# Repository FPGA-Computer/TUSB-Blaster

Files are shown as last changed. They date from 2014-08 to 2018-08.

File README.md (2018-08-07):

The TUSB3410 USB stack was loosely based on Micah Dowty's polling based
USB driver, but was heavily modifed by me using TI's app notes and
source code examples. The resulting code is a mix of interrupt code and
polling. 

This is a clone of Altera USB Blaster based on the work of Kolja Waschk,
ixo.de. The code is ported to TI TUSB3410 USB to Serial converter chip
which is found in TI's MSP430 programmers and some very old cell phone
USB Serial interface dongles. 

TUSB3410 has a very slow microcontroller core. There are much better
chips out there. This is meant to serve as a demo of the USB stack and
to show that the chip can works as a USB JTAG device for OpenOCD and USB
Blaster clone in less than 3kB firmware.

TUSB3410 has onchip SRAM for firmware and you'll need to use my command
line util: load3410.exe to download its firmware.  Use libusb to make up a
.inf file/driver for it to stop window popup asking for drivers.

TI's apps loader util can also be used as an alternative.

License: Individual source files without copyright notices are written
by me and are distributed under GPL ver 2 or newer.

TUSB source code is compiled with SDCC 3.3.  I used Programmer's Notepad
as my IDE.  Win32 Util can be compileed with Pelles C for windows.

TUSB Blaster schematic/layout are Eagle CAD 6.5.0 files.

Project page: http://hw-by-design.blogspot.com/2018/08/tusb-blaster.html

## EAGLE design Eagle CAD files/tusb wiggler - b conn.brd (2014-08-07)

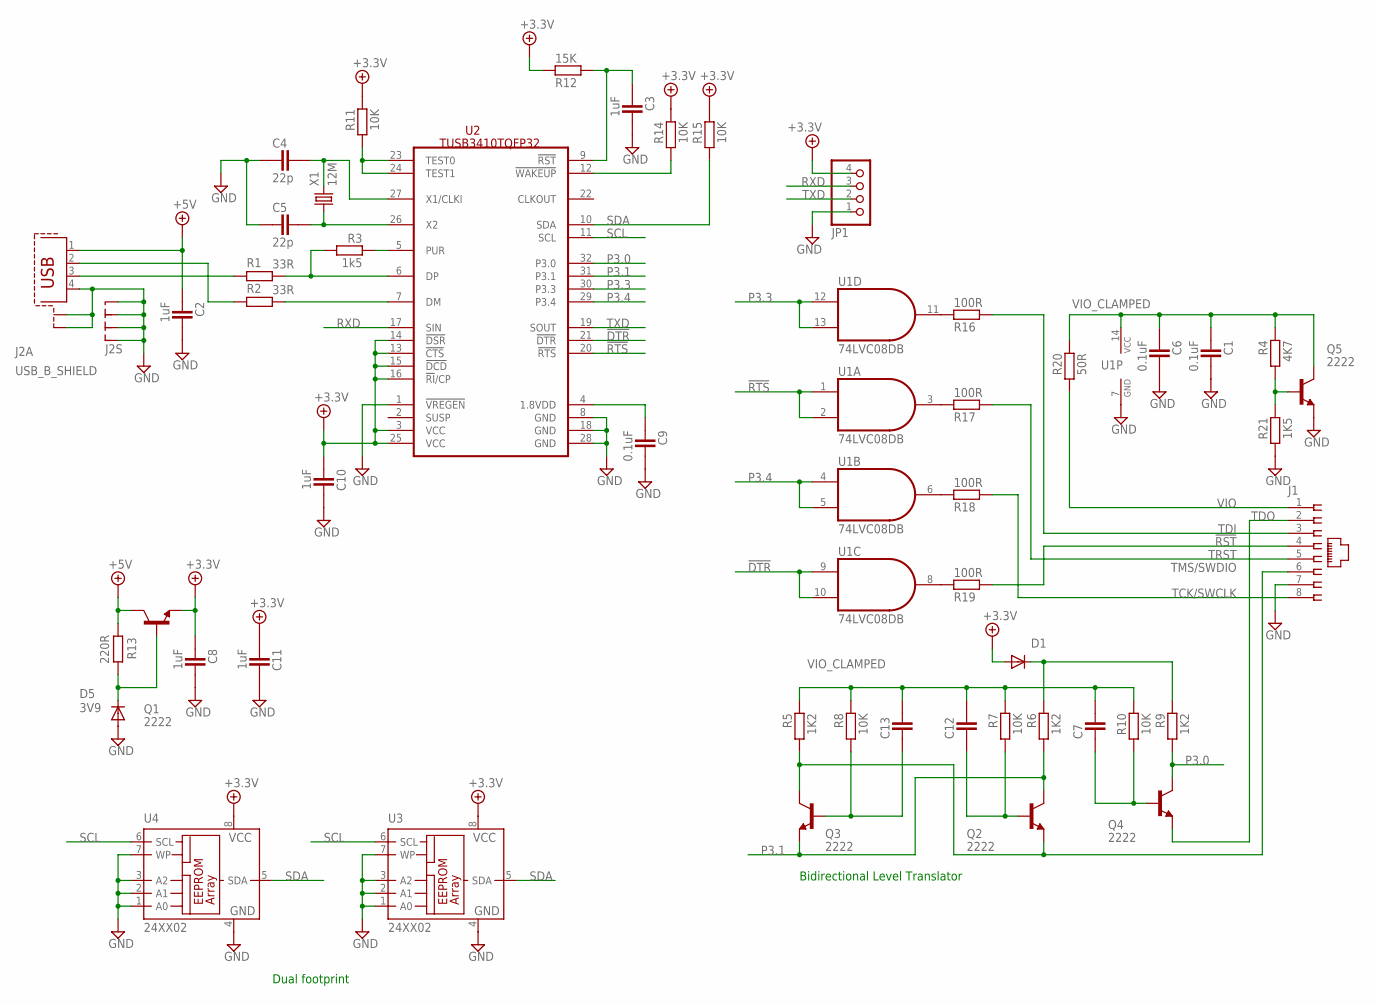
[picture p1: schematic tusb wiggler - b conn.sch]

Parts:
C1: 0.1uF; CAPC3215X168N
C2, C3, C8, C10, C11: 1uF; CAPC1608X92N
C4, C5: 22p; CAP2012X70N
C6: 0.1uF; CAPC1608X92N
C7, C12, C13: CAPACITOR_0805N; CAP2012X70N
C9: 0.1uF; CAP2012X70N
D1: DIODE-SOD110-W; SOD110-W
D5: 3V9; MELF-MLL41
J1: 520426-4
J2: USB_B_SHIELD; PN61729-S
JP1: PINHD-1X4_2.54; 1X04
Q1, Q2, Q3, Q4, Q5: 2222; SOT95P280X135-3N
R1, R2: 33R; RESC1608X55N
R3: 1k5; RESC1608X55N
R4: 4K7; RESC1608X55N
R5, R6, R9: 1K2; RESC1608X55N
R7, R8, R10, R11, R14, R15: 10K; RESC1608X55N
R12: 15K; RESC1608X55N
R13: 220R; RESC1608X55N
R16, R17, R18, R19: 100R; RESC3115X70N
R20: 50R; RESC1608X55N
R21: 1K5; RESC1608X55N
U1: 74LVC08DB; TSSOP14
U2: TUSB3410TQFP32; TQFP32-08
U3: 24XX02; TSSOP8
U4: 24XX02; SO-08
X1: 12M; HC49UP

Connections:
!DTR: U1.9 (I0), U1.10 (I1), U2.21 (!DTR)
!RST: J1.4, R19.2
!RTS: U1.1 (I0), U1.2 (I1), U2.20 (!RTS)
+3.3V: C8.1, C10.1, C11.1, D1.A, JP1.4, Q1.2 (E), R11.1, R12.1, R14.1, R15.1, U2.3 (VCC), U2.13 (!CTS), U2.14 (!DSR), U2.15 (!DCD), U2.16 (!RI!/CP), U2.25 (VCC), U3.8 (VCC), U4.8 (VCC)
+5V: C2.1, J2.1, Q1.3 (C), R13.1
GND: C1.2, C2.2, C3.2, C4.1, C5.1, C6.2, C8.2, C9.2, C10.2, C11.2, D5.A, J1.7, J2.4, J2.G1 (S1), J2.G2 (S1), J2.G3 (S2), J2.G4 (S2), J2.G5 (S3), J2.G6 (S4), JP1.1, Q5.2 (E), R21.2, U1.7 (GND), U2.1 (!VREGEN), U2.8 (GND), U2.18 (GND), U2.28 (GND), U3.1 (A0), U3.2 (A1), U3.3 (A2), U3.4 (GND), U3.7 (WP), U4.1 (A0), U4.2 (A1), U4.3 (A2), U4.4 (GND), U4.7 (WP)
unnamed: J2.3, R1.1
unnamed: C12.1, Q2.1 (B), R7.2
unnamed: C7.1, Q4.1 (B), R10.2
unnamed: C13.1, Q3.1 (B), R8.2
unnamed: R19.1, U1.8 (O)
unnamed: R11.2, U2.23 (TEST0), U2.24 (TEST1)
unnamed: C3.1, R12.2, U2.9 (!RST)
unnamed: R16.1, U1.11 (O)
unnamed: R17.1, U1.3 (O)
unnamed: R18.1, U1.6 (O)
unnamed: Q5.1 (B), R4.2, R21.1
unnamed: D1.C, R6.1, R9.1
unnamed: R14.2, U2.12 (!WAKEUP)
unnamed: J2.2, R2.1
unnamed: R1.2, R3.2, U2.6 (DP)
unnamed: R2.2, U2.7 (DM)
unnamed: D5.C, Q1.1 (B), R13.2
unnamed: C4.2, U2.27 (X1/CLKI), X1.2
unnamed: C5.2, U2.26 (X2), X1.1
unnamed: C9.1, U2.4 (1.8VDD)
unnamed: R3.1, U2.5 (PUR)
P3.0: Q4.3 (C), R9.2, U2.32 (P3.0)
P3.1: Q2.3 (C), Q3.2 (E), R6.2, U2.31 (P3.1)
P3.3: U1.12 (I0), U1.13 (I1), U2.30 (P3.3)
P3.4: U1.4 (I0), U1.5 (I1), U2.29 (P3.4)
RXD: JP1.3, U2.17 (SIN)
SCL: U2.11 (SCL), U3.6 (SCL), U4.6 (SCL)
SDA: R15.2, U2.10 (SDA), U3.5 (SDA), U4.5 (SDA)
TCK/SWCLK: J1.8, R18.2
TDI: J1.3, R16.2
TDO: J1.2, Q4.2 (E)
TMS/SWDIO: J1.6, Q2.2 (E), Q3.3 (C), R5.2
TRST: J1.5, R17.2
TXD: JP1.2, U2.19 (SOUT)
VIO: J1.1, R20.2
VIO_CLAMPED: C1.1, C6.1, C7.2, C12.2, C13.2, Q5.3 (C), R4.1, R5.1, R7.1, R8.1, R10.1, R20.1, U1.14 (VCC)

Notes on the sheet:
Bidirectional Level Translator
Dual footprint

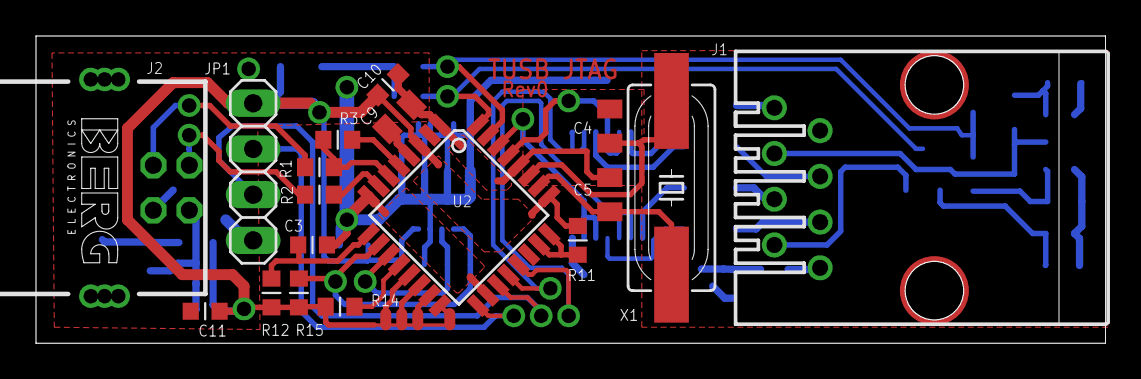
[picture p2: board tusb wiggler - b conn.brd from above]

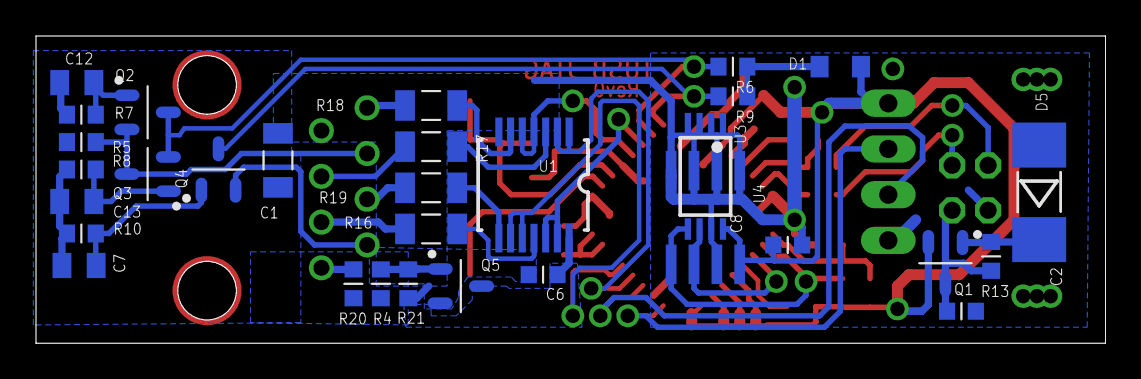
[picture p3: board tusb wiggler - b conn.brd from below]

Board: 2 copper layers, 59.4 x 17.1 mm, 49 parts (31 on the bottom side), 42 nets.

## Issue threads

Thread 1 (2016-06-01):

Porting to EFM8UB1 MCU ?

gh-jmg, 2016-06-01:
This looks a very cool project, but the TUSB3410 is quite expensive ($6+), and needs a Crystal.
Since you started this, SiLabs have released low cost 1T 8051 USB devices, that may be a better fit ?

I also see here http://ixo-jtag.sourceforge.net/archive/ixo_de_usb_jtag.html
that author started C8051F32x/F34x porting some years back, and those parts are predecessors to the EFM8UB1. (earliest ones were 24MHz SysCLK, 48MHz USB, newer are 48MHz for both CPU & USB)

Mouser shows EFM8UB10F8G-C-QFN20 for **81c 1+**
There are also 8k, 16k choices and QFN20, QFN28 or QSOP24 packages.
The newest EFM8UB1 (2016) also have a boot-loader, allowing simpler firmware updates.

I've been looking to see if the SPI port can be used dynamically for the byte-level ByteBlaster, but this will need some testing on the hand-over details between Bit-Mode and Byte-Mode.
SPI has a 4 byte FIFO and can do 48MHz/(2 * (SPI0CKR + 1)) bit rates (suggests 12MHz max), so that should manage the bulk transfers of JTAG well.

Software-only JTAG is of course simpler, and could be used for proof of concept work.

FPGA-Computer, 2016-08-21:
I actually used EFM8UB1F16 chips in here https://github.com/FPGA-Computer/Battery-Analyzer
Just that the project hasn't progressed to the point of working firmware.  Things are in limbo.

I don't have much interest in OpenOCD these days ever since they have broken a few things intentionally.  This project is released as is as there are few sources of USB drivers outside of the official source code.

Closed 2016-08-21.

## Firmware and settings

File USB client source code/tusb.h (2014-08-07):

/*-------------------------------------------------------------------------
   Register Declarations for the Texas Instruments TUSB3210/3410 Processors

   TUSB3410 definitions added by Micah Dowty / micah@navi.cx (May 2004)
   Written By -  Michael Petruzelka / michael@root.at (December 2001)
   based on 8051.h from Bela Torok / bela.torok@kssg.ch (July 2000)

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
   In other words, you are welcome to use, share and improve this program.
   You are forbidden to forbid anyone else to use, share and improve
   what you give them.   Help stamp out software-hoarding!
-------------------------------------------------------------------------*/

#ifndef REGTUSB_H
#define REGTUSB_H

/*  BYTE Register  */
 __sfr __at 0x80 P0   ;
 __sfr __at 0x81 SP   ;
 __sfr __at 0x82 DPL  ;
 __sfr __at 0x83 DPH  ;
 __sfr __at 0x87 PCON ;
 __sfr __at 0x88 TCON ;
 __sfr __at 0x89 TMOD ;
 __sfr __at 0x8A TL0  ;
 __sfr __at 0x8B TL1  ;
 __sfr __at 0x8C TH0  ;
 __sfr __at 0x8D TH1  ;
 __sfr __at 0x90 P1   ;
 __sfr __at 0x98 SCON ;
 __sfr __at 0x99 SBUF ;
 __sfr __at 0xA0 P2   ;
 __sfr __at 0xA8 IE   ;
 __sfr __at 0xB0 P3   ;
 __sfr __at 0xB8 IP   ;
 __sfr __at 0xD0 PSW  ;
 __sfr __at 0xE0 ACC  ;
 __sfr __at 0xF0 B    ;


/*  BIT Register  */
/* P0 */
 __sbit __at 0x80 P0_0 ;
 __sbit __at 0x81 P0_1 ;
 __sbit __at 0x82 P0_2 ;
 __sbit __at 0x83 P0_3 ;
 __sbit __at 0x84 P0_4 ;
 __sbit __at 0x85 P0_5 ;
 __sbit __at 0x86 P0_6 ;
 __sbit __at 0x87 P0_7 ;

/*  TCON  */
 __sbit __at 0x88 IT0  ;
 __sbit __at 0x89 IE0  ;
 __sbit __at 0x8A IT1  ;
 __sbit __at 0x8B IE1  ;
 __sbit __at 0x8C TR0  ;
 __sbit __at 0x8D TF0  ;
 __sbit __at 0x8E TR1  ;
 __sbit __at 0x8F TF1  ;

/* P1 */
 __sbit __at 0x90 P1_0 ;
 __sbit __at 0x91 P1_1 ;
 __sbit __at 0x92 P1_2 ;
 __sbit __at 0x93 P1_3 ;
 __sbit __at 0x94 P1_4 ;
 __sbit __at 0x95 P1_5 ;
 __sbit __at 0x96 P1_6 ;
 __sbit __at 0x97 P1_7 ;

/*  SCON  */
 __sbit __at 0x98 RI   ;
 __sbit __at 0x99 TI   ;
 __sbit __at 0x9A RB8  ;
 __sbit __at 0x9B TB8  ;
 __sbit __at 0x9C REN  ;
 __sbit __at 0x9D SM2  ;
 __sbit __at 0x9E SM1  ;
 __sbit __at 0x9F SM0  ;

/* P2 */
 __sbit __at 0xA0 P2_0 ;
 __sbit __at 0xA1 P2_1 ;
 __sbit __at 0xA2 P2_2 ;
 __sbit __at 0xA3 P2_3 ;
 __sbit __at 0xA4 P2_4 ;
 __sbit __at 0xA5 P2_5 ;
 __sbit __at 0xA6 P2_6 ;
 __sbit __at 0xA7 P2_7 ;

/*  IE   */
 __sbit __at 0xA8 EX0  ;
 __sbit __at 0xA9 ET0  ;
 __sbit __at 0xAA EX1  ;
 __sbit __at 0xAB ET1  ;
 __sbit __at 0xAC ES   ;
 __sbit __at 0xAF EA   ;

/*  P3  */
 __sbit __at 0xB0 P3_0 ;
 __sbit __at 0xB1 P3_1 ;
 __sbit __at 0xB2 P3_2 ;
 __sbit __at 0xB3 P3_3 ;
 __sbit __at 0xB4 P3_4 ;
 __sbit __at 0xB5 P3_5 ;
 __sbit __at 0xB6 P3_6 ;
 __sbit __at 0xB7 P3_7 ;

 __sbit __at 0xB0 RXD  ;
 __sbit __at 0xB1 TXD  ;
 __sbit __at 0xB2 INT0 ;
 __sbit __at 0xB3 INT1 ;
 __sbit __at 0xB4 T0   ;
 __sbit __at 0xB5 T1   ;
 __sbit __at 0xB6 WR   ;
 __sbit __at 0xB7 RD   ;

/*  IP   */
 __sbit __at 0xB8 PX0  ;
 __sbit __at 0xB9 PT0  ;
 __sbit __at 0xBA PX1  ;
 __sbit __at 0xBB PT1  ;
 __sbit __at 0xBC PS   ;

/*  PSW   */
 __sbit __at 0xD0 P    ;
 __sbit __at 0xD1 F1   ;
 __sbit __at 0xD2 OV   ;
 __sbit __at 0xD3 RS0  ;
 __sbit __at 0xD4 RS1  ;
 __sbit __at 0xD5 F0   ;
 __sbit __at 0xD6 AC   ;
 __sbit __at 0xD7 CY   ;

/* BIT definitions for bits that are not directly accessible */
/* PCON bits */
#define IDL             0x01
#define PD              0x02
#define GF0             0x04
#define GF1             0x08
#define SMOD            0x80

/* TMOD bits */
#define T0_M0           0x01
#define T0_M1           0x02
#define T0_CT           0x04
#define T0_GATE         0x08
#define T1_M0           0x10
#define T1_M1           0x20
#define T1_CT           0x40
#define T1_GATE         0x80

#define T0_MASK         0x0F
#define T1_MASK         0xF0

/* Interrupt vectors */
#define VECTOR_NONE         0x00
#define VECTOR_OEP1         0x12
#define VECTOR_OEP2         0x14
#define VECTOR_OEP3         0x16
#define VECTOR_IEP1         0x22
#define VECTOR_IEP2         0x24
#define VECTOR_IEP3         0x26
#define VECTOR_STPOW        0x30
#define VECTOR_SETUP        0x32
#define VECTOR_RESR         0x38
#define VECTOR_SUSR         0x3A
#define VECTOR_RSTR         0x3C
#define VECTOR_I2C_TXE      0x40
#define VECTOR_I2C_RXF      0x42
#define VECTOR_IEP0         0x44
#define VECTOR_OEP0         0x46
#define VECTOR_UART_STATUS  0x50
#define VECTOR_UART_MODEM   0x52
#define VECTOR_UART_RXF     0x60
#define VECTOR_UART_TXE     0x62
#define VECTOR_DMA1         0x80
#define VECTOR_DMA3         0x84

struct endpoint_descriptor {
  unsigned char config;
  unsigned char x_base;
  unsigned char x_count;
  unsigned char reserved[2];
  unsigned char y_base;
  unsigned char y_count;
  unsigned char buffer_size;
};

/* An array with all endpoint descriptors. This is a departure
 * from this header file's old method of naming all registers
 * separately, but using an array here can really make other
 * parts of the app cleaner, even if it means not using the exact
 * same register names as the data sheet.
 */
volatile __xdata __at 0xFF08 struct endpoint_descriptor EDB[16];

/* Indexes into EDB */
#define EDB_OEP1  0
#define EDB_OEP2  1
#define EDB_OEP3  2
#define EDB_IEP1  8
#define EDB_IEP2  9
#define EDB_IEP3  10

/* Endpoint Configuration Bits */
#define USBIE    (1<<2)                 /* USB interrupt enable */
#define STALL    (1<<3)                 /* Stall indicator bit */
#define DBUF     (1<<4)                 /* Double buffer enable */
#define TOGLE    (1<<5)                 /* Data0,Data1 toggle status */
#define ISO      (1<<6)                 /* =0 Only non Isochronous transfer supported */
#define UBME     (1<<7)                 /* UBM enable */

#define NAK	0x80
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

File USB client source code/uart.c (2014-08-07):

#include "main.h"

void uart_init()
{
  UART_MASK = 0;				/* No interrupts */
  MODECNFG = TXCNTL | SOFTSW; 	/* Transmitter on */
  MCR  = MCR_USRT;            		/* UART reset */
  MCR  = 0;                   			/* UART out of reset */
  LCR  = 0;                   			/* FIFO reset */
  LCR  = LCR_WL8 | LCR_FEN;   	/* 8-N-1, enable FIFOs */
  FCRL = 0;                   			/* No flow control */
  MSR  = 0xFF;                			/* Reset modem status */
  DLH = 0;
  DLL = 8;

}

void uart_set_speed(int divisor)
{
  DLH = divisor >> 8;
  DLL = divisor & 0xFF;
}

void uart_write(char c)
{
  while (!(LSR & LSR_TxE))
    /* */;
  TDR = c;
}

char uart_read()
{
  while (!(LSR & LSR_RxF))
    /* */;
  return RDR;
}

void putchar(char c) 
{
  uart_write(c);

  /* Convert \n into \n\r */
  if (c == '\n')
    uart_write('\r');
}

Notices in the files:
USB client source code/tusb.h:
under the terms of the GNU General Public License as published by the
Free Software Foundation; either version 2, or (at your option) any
